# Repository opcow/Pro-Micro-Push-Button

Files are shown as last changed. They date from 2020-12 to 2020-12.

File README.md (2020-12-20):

# 3D Printable Pro Micro Based Push Button

This is a single pushbutton. You could use it as a push to talk button, a jump button for games that are playable with 1 button (e.g. I use it for the game Geometry Dash), or whatever. The button can emulate any combination of keyboard key, mouse button, and game controller button inputs.

This design fits my Chinese Pro Micro knockoff perfectly, but may not fit every board as well. A step file of the assembly is included for easy modification.

I print the conical cap pointy end down using a brim for bed adhesion. Supports are not needed for any parts.

I use Cura's dynamic quality at 0.16 layer height. This setting adjusts the layer height based on model detail. If your slicer doesn't offer this functionality, you might want to use a finer print setting for better fitting threads. I've found that my threads fit best using Cura and also work well using PrusaSlicer. ideaMaker didn't make good threads in my tests, but YMMV. I didn't test any other slicers.

Non-printable parts needed:

* [Pro Micro Arduino microcontroller](https://deskthority.net/wiki/Arduino_Pro_Micro).
* A bit of wire.
* 1 micro switch

I use the kind of micro switch found in a computer mouse. A mounting adapter for this kind of switch is included. A momentary pushbutton could be used as well by making an adapter with, for example, a round 16 mm hole. Import the included step file into your CAD software to make your own button/switch adapter.

STL files are included for a cyclindrical Pro Micro case sans the lower threads for the lower cap. This was left over from the prototype design, but I left it in as someone may find it useful. The upper pieces are compatible if you don't care about the lower cap witch serves as a longer grip and captures the USB cable, but is optional. The lower ring can also be used is place of the lower cap.

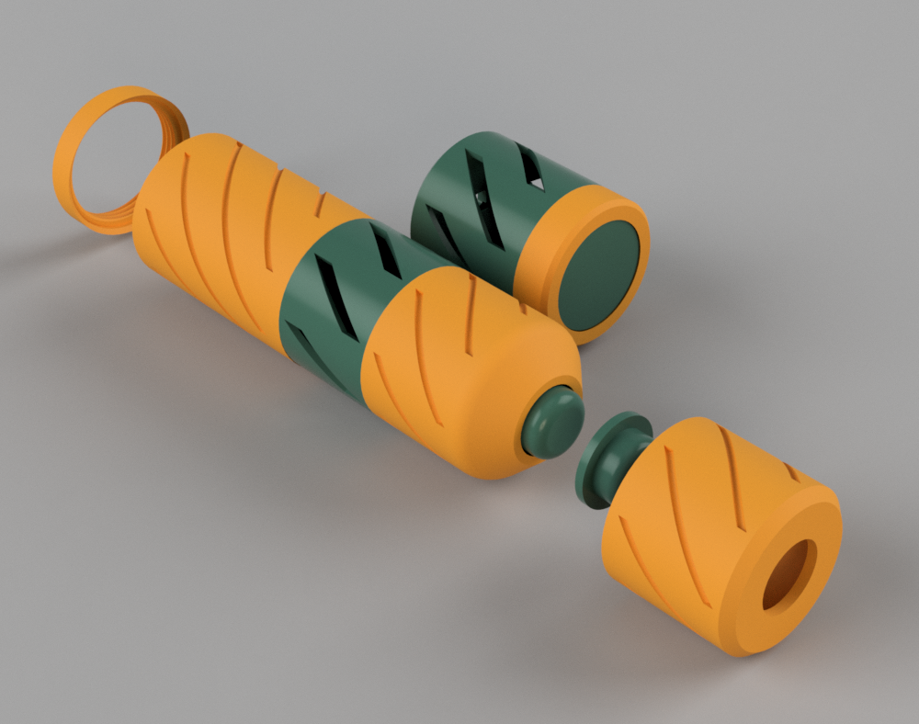
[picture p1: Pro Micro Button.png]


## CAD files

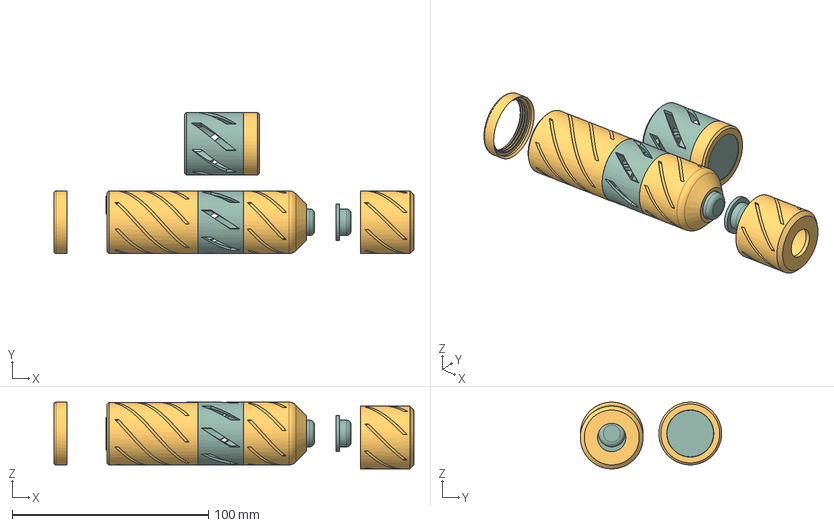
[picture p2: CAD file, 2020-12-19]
Pro Micro Button.step
183.5 x 72.0 x 34.0 mm
case-a
collar
conical-cap
extended-button
short-button
micro-switch-adapter
switch-mount
plug
flat-cap
lower-ring
cover
lower-cap
case-b

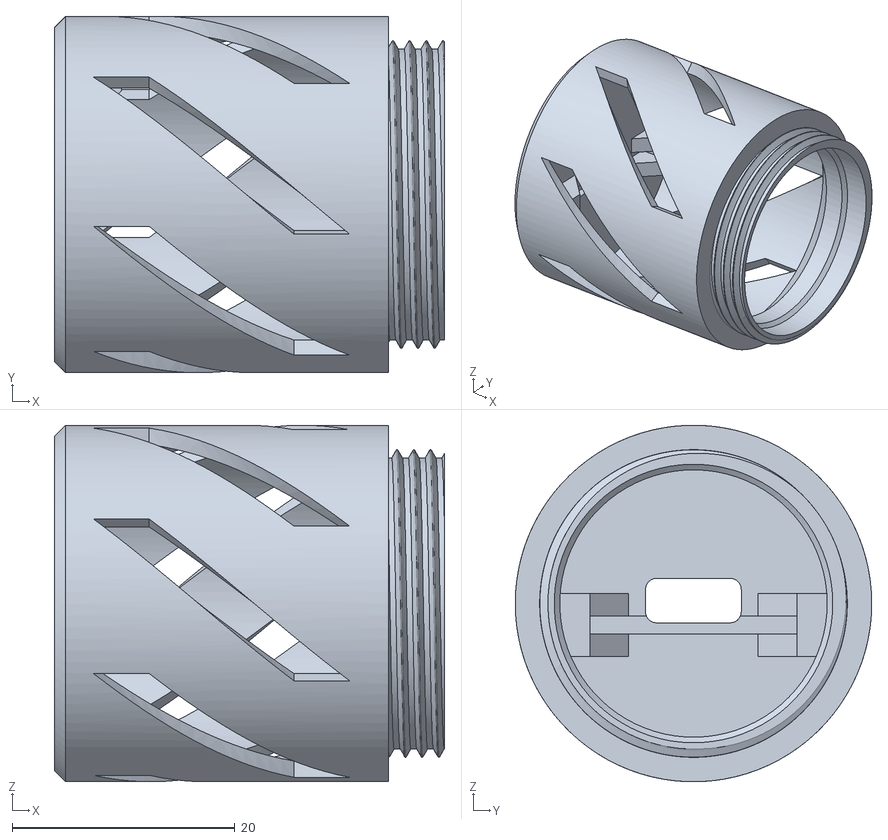
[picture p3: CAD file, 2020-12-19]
case-b.stl
35.0 x 32.0 x 32.0

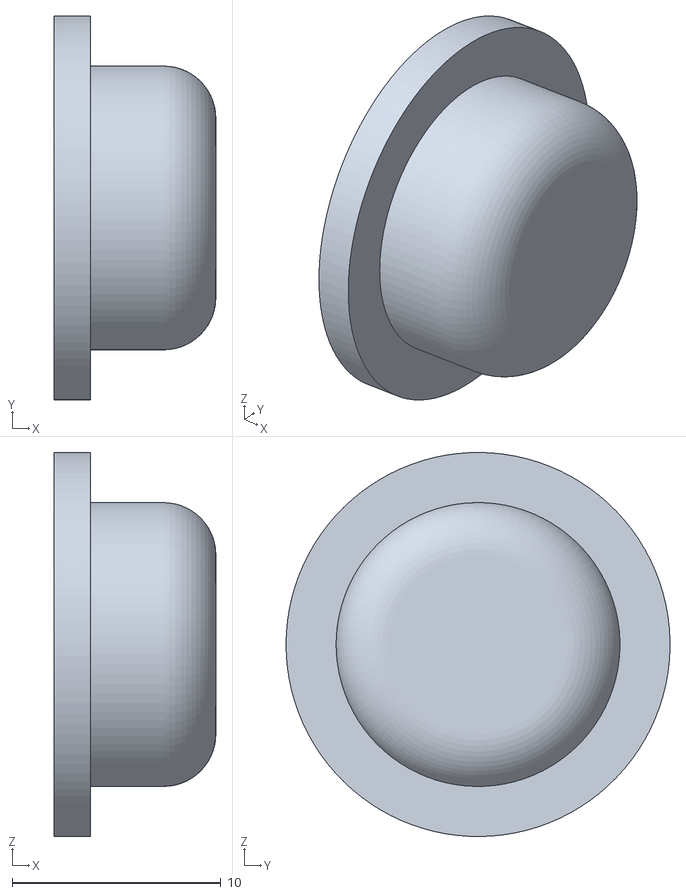
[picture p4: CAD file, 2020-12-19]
short-button.stl
7.75 x 18.4 x 18.4

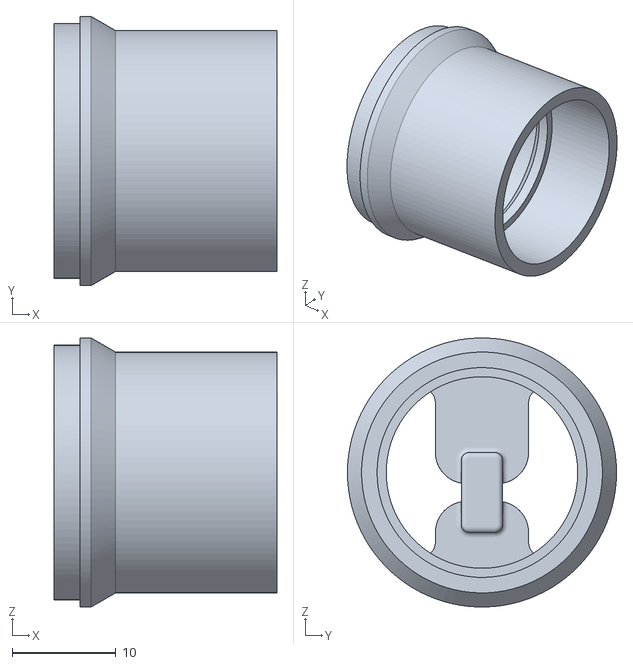
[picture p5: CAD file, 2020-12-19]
switch-mount.stl
21.5 x 26.0 x 26.0

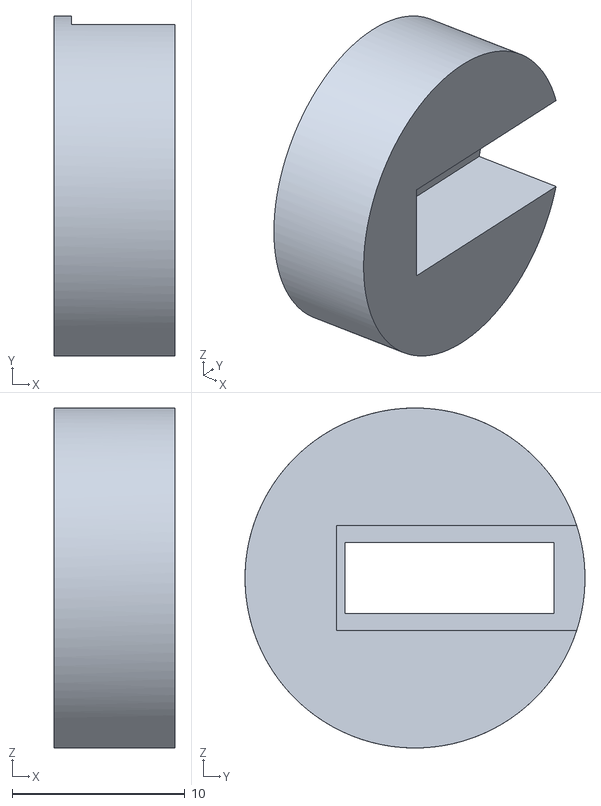
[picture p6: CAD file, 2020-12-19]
micro-switch-adapter.stl
7.00 x 19.7 x 19.7

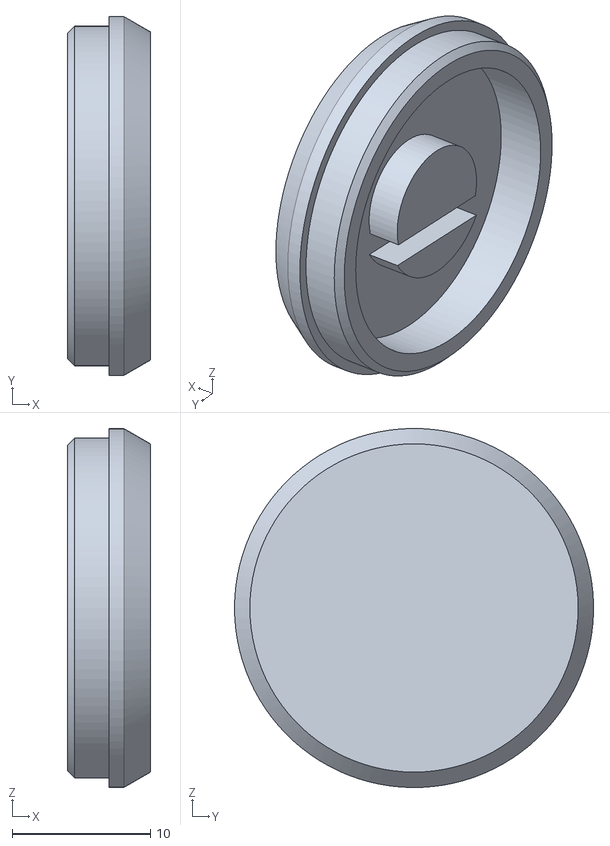
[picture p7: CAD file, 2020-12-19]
plug.stl
6.00 x 26.0 x 26.0

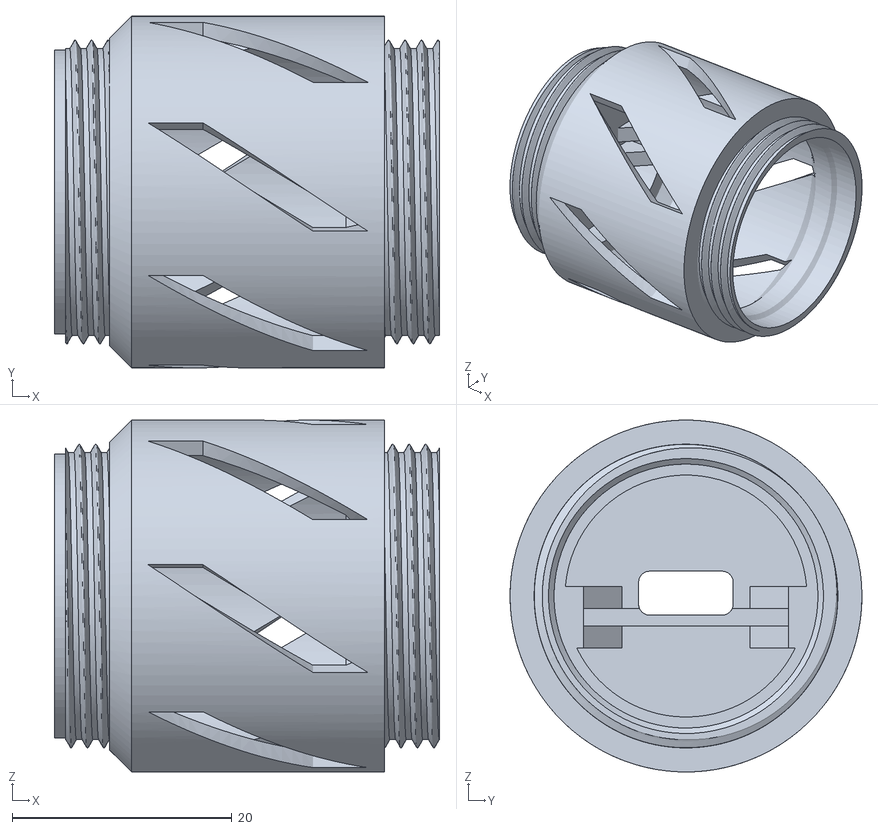
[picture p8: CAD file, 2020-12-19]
case-a.stl
35.0 x 32.0 x 32.0

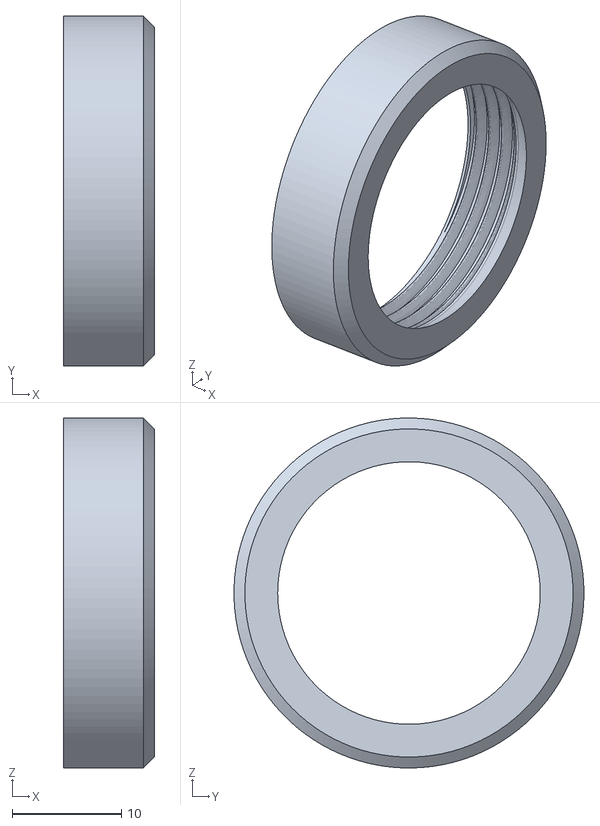
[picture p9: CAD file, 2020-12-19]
collar.stl
8.30 x 32.0 x 32.0

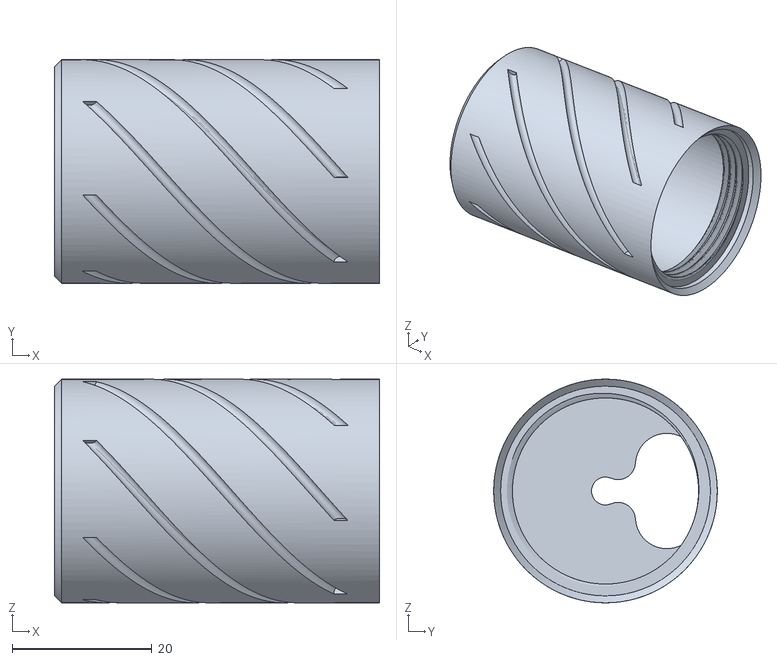
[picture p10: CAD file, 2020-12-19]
lower-cap.stl
46.5 x 32.0 x 32.0

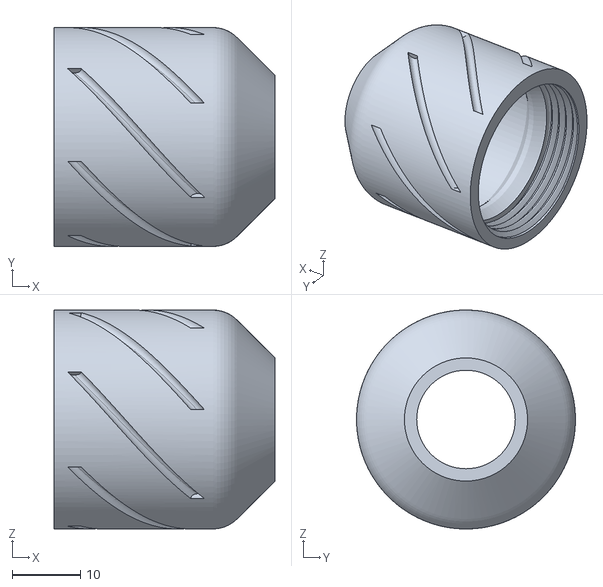
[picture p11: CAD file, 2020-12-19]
conical-cap.stl
32.3 x 32.0 x 32.0

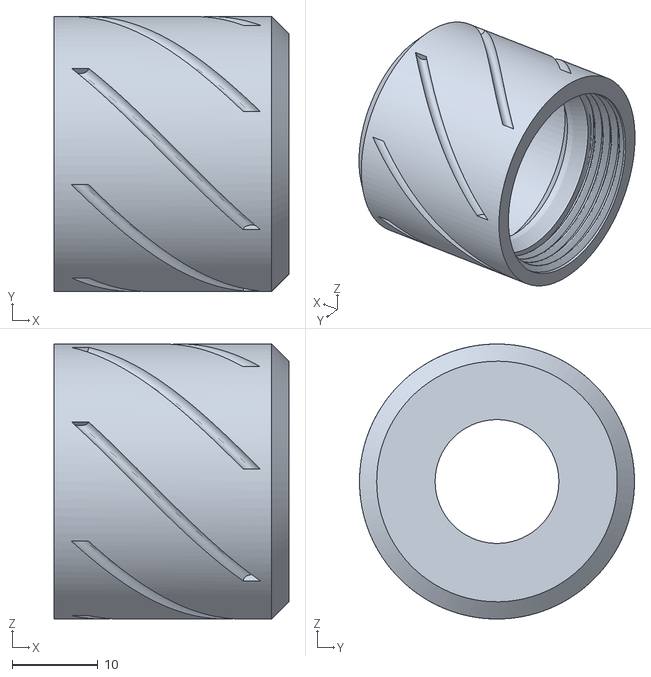
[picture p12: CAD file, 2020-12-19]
flat-cap.stl
27.3 x 32.0 x 32.0

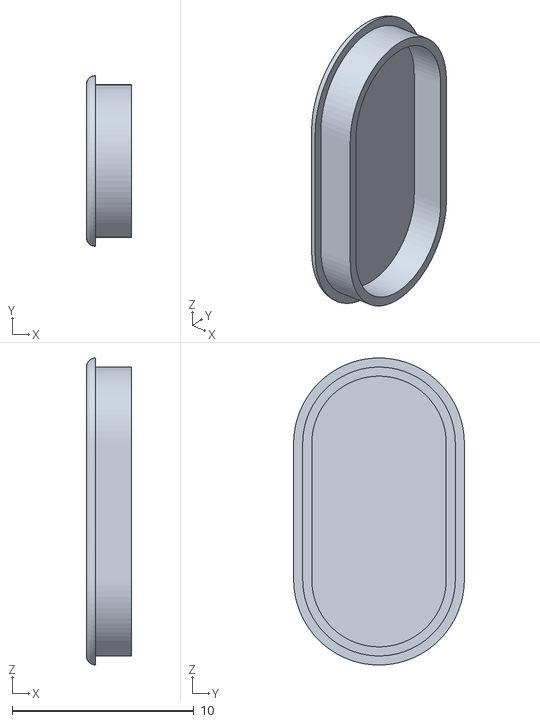
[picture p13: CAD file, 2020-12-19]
cover.stl
2.50 x 9.40 x 16.9

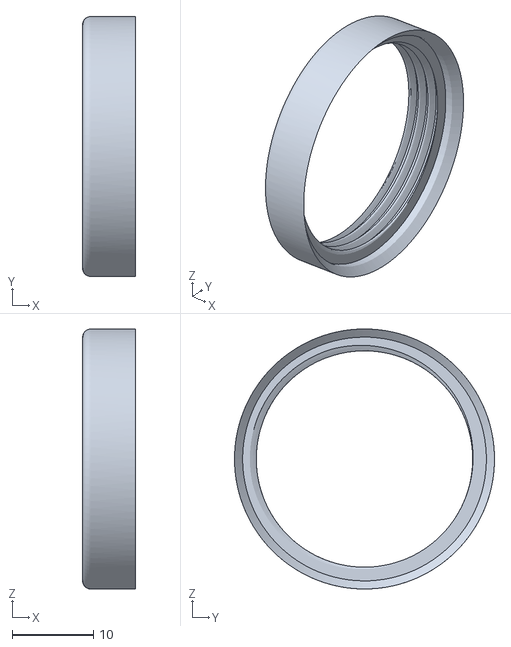
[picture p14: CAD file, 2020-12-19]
lower-ring.stl
6.50 x 32.0 x 32.0

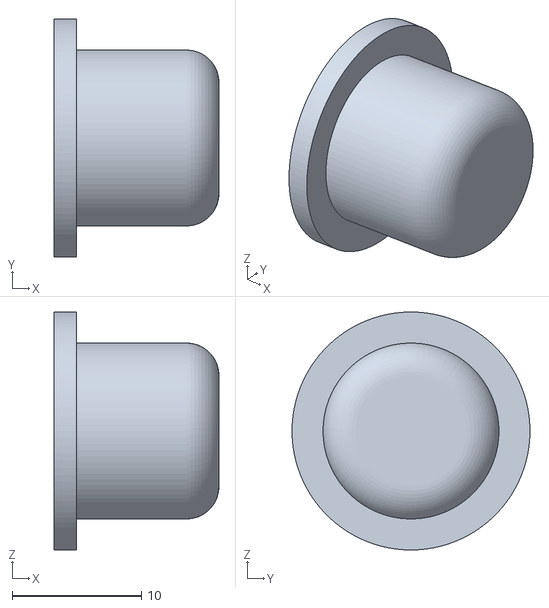
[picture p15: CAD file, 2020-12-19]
extended-button.stl
12.8 x 18.4 x 18.4

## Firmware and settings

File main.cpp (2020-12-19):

// #include <Arduino.h>
#include <Keyboard.h> // The main library for sending keystrokes.
// #include <Joystick.h>

bool gKeyDown = false;

#define PINS 14
#define ENABLE_ANALOG1 false
int X1 = A0;
int Y1 = A1;

// Joystick_ Joystick(JOYSTICK_DEFAULT_REPORT_ID, JOYSTICK_TYPE_GAMEPAD, PINS, 0, 
//   true, true, false, false, false, false, false, false, false, false, false);

void setup()
{
  pinMode(2, INPUT);
  digitalWrite(2, HIGH);
  Keyboard.begin(); // Initialise the library.
}

// Loop around waiting for a button press on pin 2.
// When the button is pressed, go to the function triggerAutomation.
void loop() 
{
  if(digitalRead(2) == LOW && !gKeyDown)
  {
    Keyboard.press(KEY_LEFT_CTRL);    // Press and hold the left Crtl key.
    Keyboard.press(KEY_LEFT_GUI);     // Press and hold the left Windows key.
    Keyboard.press(KEY_LEFT_ALT);     // Press and hold the left Alt key.
    // Keyboard.press(KEY_UP_ARROW);
    gKeyDown = true;
  } else if(digitalRead(2) == HIGH && gKeyDown)
  {
    Keyboard.releaseAll();
    gKeyDown = false;
    //delay(200);
   }
}

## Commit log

2020-12-19 add all the things
    [Pro Micro Button.step, case-a.stl, case-b.stl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]
2020-12-19 added cpp code, renamed micro switch adapter stl
    [Pro Micro Button.step, micro-switch-adapter.stl]
2020-12-19 printing info
